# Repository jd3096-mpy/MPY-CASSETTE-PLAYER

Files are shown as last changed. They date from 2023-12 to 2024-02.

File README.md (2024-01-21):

# MPY-CASSETTE-PLAYER

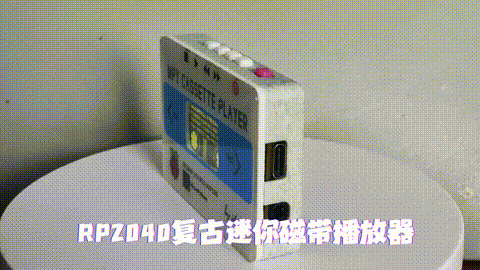
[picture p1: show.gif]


2023年最后一个项目啦，今年尝试了画PCB和3d建模，已经达到了HELLO WORLD水平，可喜可贺！

可识别的封面需要手动添加，主打一个情怀，分辨率要求240x75，添加工具也在文件夹工具脚本下面

img下所有素材都是我用ps一点一点抠的

首发DF论坛，参加树莓派活动！

## 按键功能简介

*按住STOP键，再按POWER键开机则进入boot下载模式，可直接拖拽UF2下载固件*

| | STOP | PLAY | N/V+ | N/V- | POWER |
| ---- | --- | --- | --- | --- | --- |
| 短按 | 暂停 | 播放 | 音量加 | 音量减 | 屏幕开关 |
| 中按 | | 切换封面/歌名 | | | 关机 |
| 长按 | 歌曲选择 | 设置菜单 | 下一首 | 上一首 | 硬关机 |

## 引脚分布

| 引脚名称 | GPIO |
| --- | ---- |
| xcs（VS1053） | 20 |
| x_reset（VS1053） | 21 |
| xdcs（VS1053） | 26 |
| dreq（VS1053） | 27 |
| sck（VS1053和tf卡公用）  | 18 |
| mosi（VS1053和tf卡公用） | 19 |
| miso（VS1053和tf卡公用） | 16 |
| cs（tf卡） | 17 |
| reset（屏幕） | 9 |
| cs（屏幕） | 7 |
| dc（屏幕） | 8 |
| bl（屏幕） | 6 |
| sck（屏幕） | 10 |
| mosi（屏幕） | 11 |
| next（按键） | 14 |
| prev（按键） | 15 |
| play（按键） | 4 |
| mode（按键） | 5 |
| SCL（AXP199） | 1 |
| SDA（AXP199） | 0 |
| IRQ（AXP199） | 2 |

## 重点的技术突破

- 自己学了mp3的编码格式，码率，ID3信息，专辑封面都能自由获取
- 感谢老李eggfly的神级助攻，画了精致的pcb并且通过修改源码让mpy文件系统支持了中文，牛哇！
- 细挖了st7789的驱动库，有个类似精灵的方法，可以在不费内存的情况下保持高速刷屏，很关键，内存终于不紧张了！
- m0dular帮重做了外壳，果然结构科学多了，致敬!
- 最后还是决定去掉了快进快退的功能，效果不好而且不是很常用

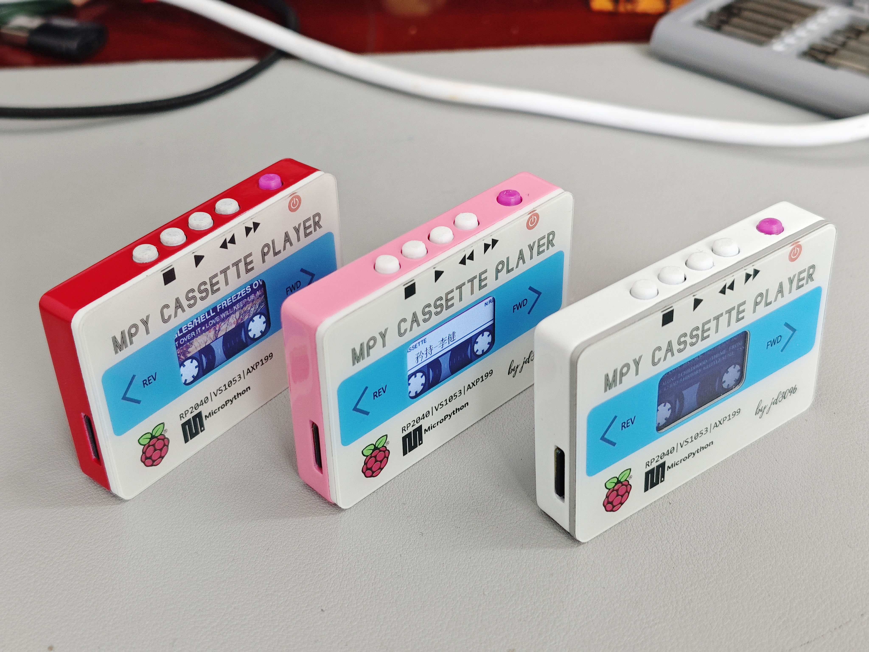
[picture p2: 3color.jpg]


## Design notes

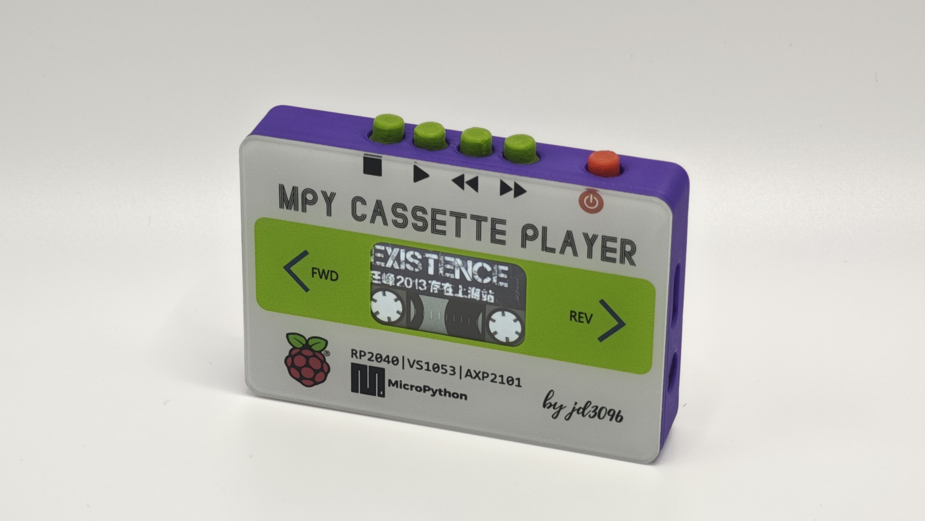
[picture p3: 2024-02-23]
EVA-1.jpg

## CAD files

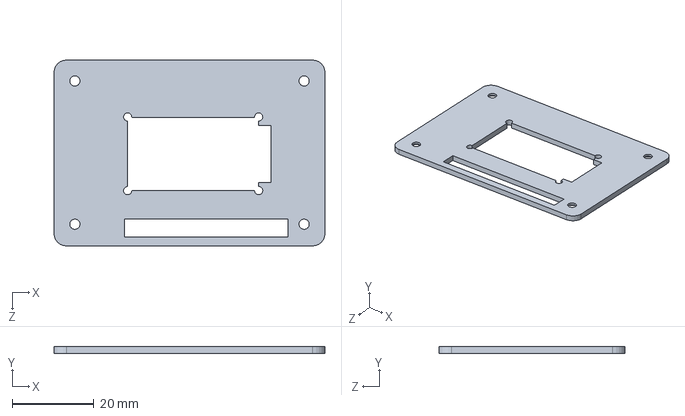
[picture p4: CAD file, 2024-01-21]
外壳/v2(好友m0dular提供)/前板.SLDPRT
66.2 x 1.60 x 45.4 mm

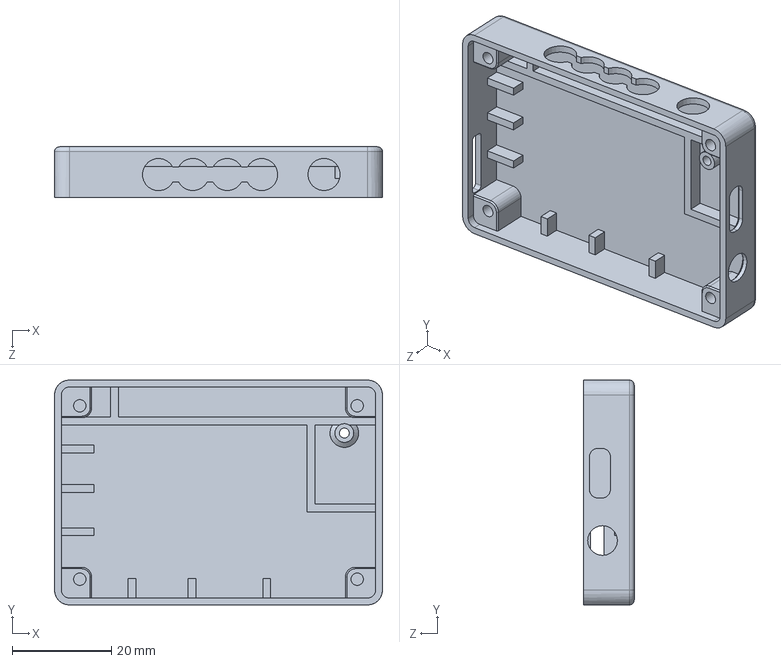
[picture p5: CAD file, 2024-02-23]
外壳/V4/底壳.SLDPRT
66.2 x 45.4 x 10.2 mm

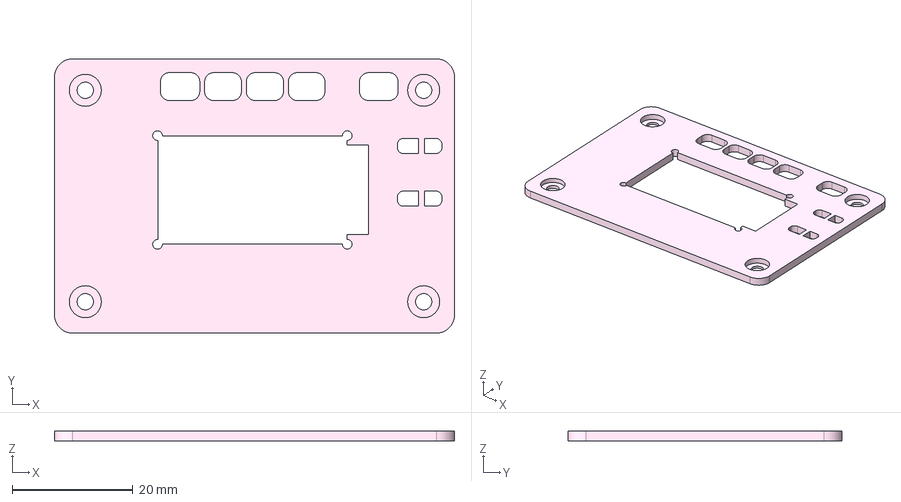
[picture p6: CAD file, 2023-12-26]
外壳/v2(好友m0dular提供)/上壳.step
66.2 x 45.4 x 1.70 mm

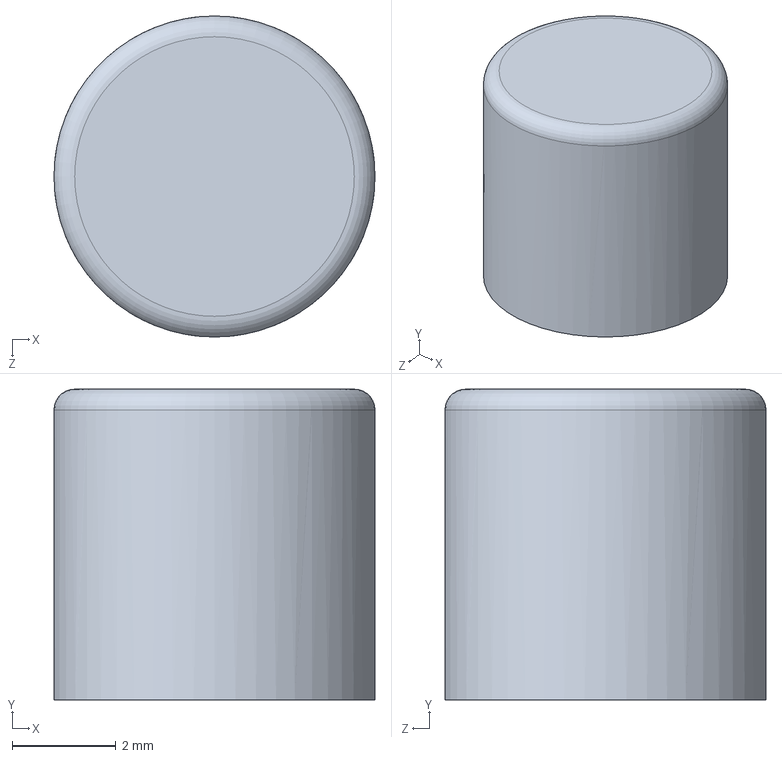
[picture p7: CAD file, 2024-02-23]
外壳/V4/按键.SLDPRT
6.20 x 6.00 x 6.20 mm

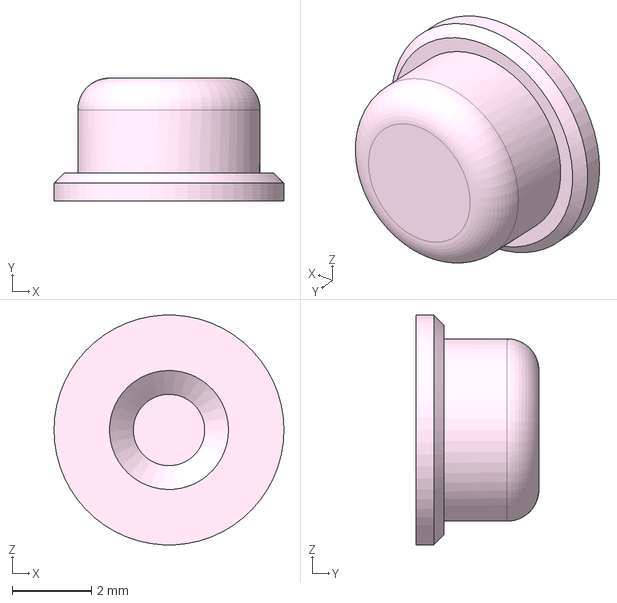
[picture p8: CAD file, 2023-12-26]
外壳/v2(好友m0dular提供)/按键.step
5.80 x 3.10 x 5.79 mm

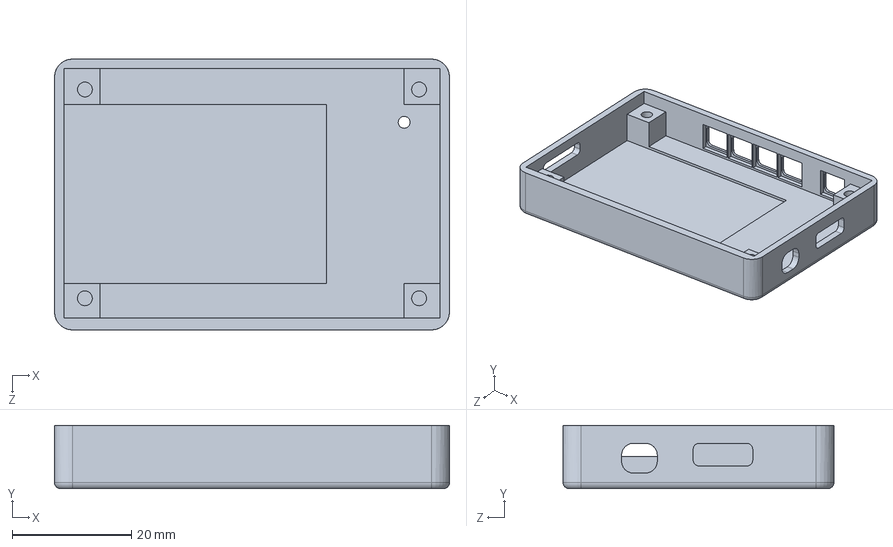
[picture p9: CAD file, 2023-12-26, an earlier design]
外壳/v1/底板.SLDPRT
66.2 x 10.6 x 45.4 mm

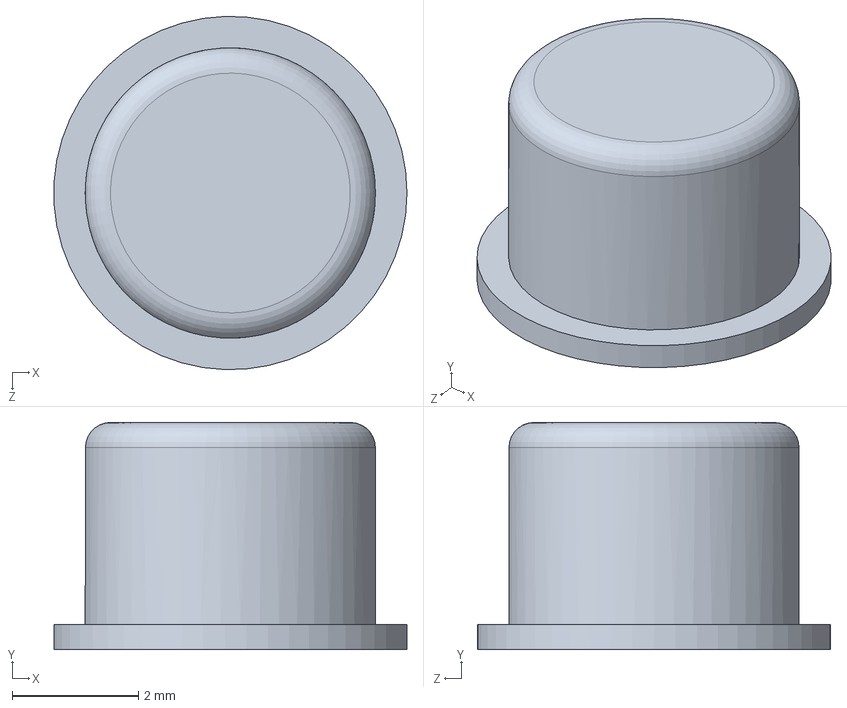
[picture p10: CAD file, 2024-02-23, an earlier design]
外壳/V3/按键.SLDPRT
5.59 x 3.60 x 5.60 mm

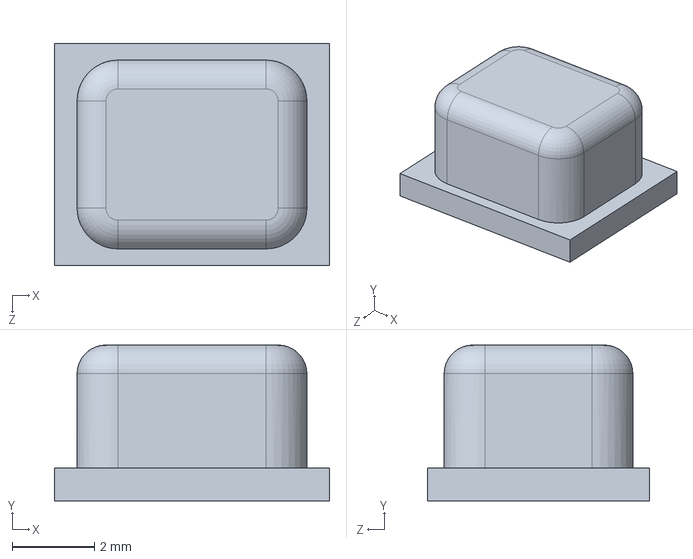
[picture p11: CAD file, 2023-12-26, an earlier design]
外壳/v1/播放按钮.SLDPRT
6.70 x 3.80 x 5.40 mm

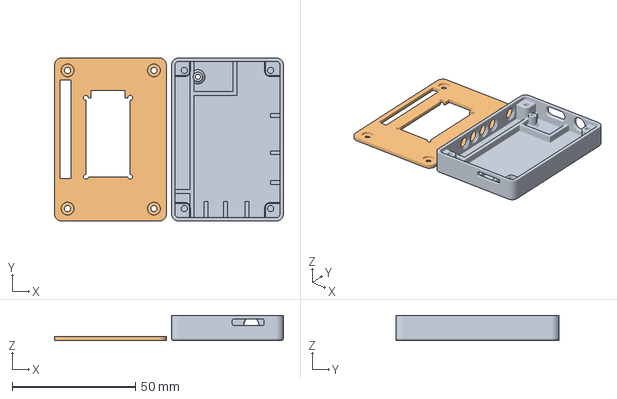
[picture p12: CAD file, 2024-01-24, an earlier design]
外壳/V3/外壳套装 按键另外打比较好.3mf
92.8 x 66.2 x 10.2 mm
底壳.stl
前板.STL

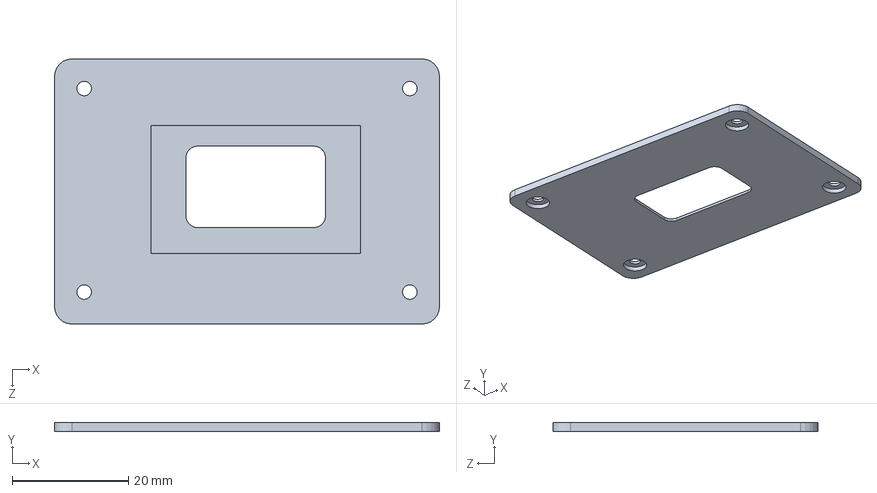
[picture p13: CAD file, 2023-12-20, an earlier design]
外壳/v1/前板.SLDPRT
66.2 x 1.60 x 45.6 mm

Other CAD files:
外壳/V4/前板.SLDPRT
外壳/v2(好友m0dular提供)/底壳.step
外壳/V3/底壳.SLDPRT
外壳/V3/底壳.stl
外壳/V3/按键.3mf
外壳/V3/按键.STL
外壳/V4/前板.STL
外壳/V4/底壳.stl
外壳/V4/按键.STL
外壳/v1/前板.STL
外壳/v1/底板.STL
外壳/v1/播放按钮.STL
外壳/v2(好友m0dular提供)/底壳.stl
外壳/v2(好友m0dular提供)/按键.SLDPRT
外壳/v2(好友m0dular提供)/按键.STL

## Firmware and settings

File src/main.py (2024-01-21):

from machine import Pin
b=Pin(4,Pin.IN,Pin.PULL_UP)

def boot_mode():
    import machine
    import st7789
    import time
    from machine import Pin
    import tft_config
    bl=Pin(6,Pin.OUT)
    bl.value(0)
    tft=tft_config.config(1)
    tft.init()
    tft.fill(0xffff)
    tft.jpg('img/update.jpg',0,0,st7789.SLOW)
    time.sleep(2)
    s=Pin(5,Pin.IN,Pin.PULL_UP)
    while s.value()==1:
        pass
    machine.bootloader(True)
    
if b.value()==0:
    boot_mode()
#----------------------MAIN-------------------------
import gc
gc.enable()
import uasyncio as asyncio
from lib.cassette import CASSETTE
gc.collect()
tape=CASSETTE()
asyncio.run(tape.main())    

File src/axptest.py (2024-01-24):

'''
@license MIT License

Copyright (c) 2022 lewis he

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
@file      AXP2101_AllFunction.py
@author    Lewis He (lewishe@outlook.com)
@date      2022-10-20

'''
from AXP2101 import *
import time

SDA = None
SCL = None
IRQ = None
I2CBUS = None

if implementation.name == 'micropython':
    from machine import Pin, SoftI2C
    SDA = 0
    SCL = 1
    IRQ = 2
    I2CBUS = SoftI2C(scl=Pin(SCL), sda=Pin(SDA))
if implementation.name == 'circuitpython':
    import digitalio
    import board
    import busio
    SDA = board.IO42
    SCL = board.IO41
    IRQ = board.IO6
    I2CBUS = busio.I2C(SCL, SDA)
pmu_flag = False
irq = None


def __callback(args):
    global pmu_flag
    pmu_flag = True
    # print('callback')


PMU = AXP2101(I2CBUS, addr=AXP2101_SLAVE_ADDRESS)

id = PMU.getChipID()
if id != XPOWERS_AXP2101_CHIP_ID:
    print("PMU is not online...")
    while True:
        pass

print('getID:%s' % hex(PMU.getChipID()))

#  Set the minimum common working voltage of the PMU VBUS input,
#  below this value will turn off the PMU
PMU.setVbusVoltageLimit(PMU.XPOWERS_AXP2101_VBUS_VOL_LIM_4V36)

#  Set the maximum current of the PMU VBUS input,
#  higher than this value will turn off the PMU
PMU.setVbusCurrentLimit(PMU.XPOWERS_AXP2101_VBUS_CUR_LIM_1500MA)

#  Get the VSYS shutdown voltage
vol = PMU.getSysPowerDownVoltage()
print('->  getSysPowerDownVoltage:%u' % vol)

#  Set VSY off voltage as 2600mV, Adjustment range 2600mV ~ 3300mV
PMU.setSysPowerDownVoltage(2600)

vol = PMU.getSysPowerDownVoltage()
print('->  getSysPowerDownVoltage:%u' % vol)

#  DC1 IMAX = 2A
#  1500~3400mV, 100mV/step, 20steps
PMU.setDC1Voltage(3300)
# print('DC1  : %s   Voltage:%u mV ' % PMU.isEnableDC1()  ? '+': '-', PMU.getDC1Voltage())
print('DC1  : {0}   Voltage:{1} mV '.format(
    ('-', '+')[PMU.isEnableDC1()], PMU.getDC1Voltage()))


#  DC2 IMAX = 2A
#  500~1200mV  10mV/step, 71steps
#  1220~1540mV 20mV/step, 17steps
PMU.setDC2Voltage(1000)
print(PMU.isEnableDC2())
print('DC2  : {0}   Voltage:{1} mV '.format(
    ('-', '+')[PMU.isEnableDC2()], PMU.getDC2Voltage()))

#  DC3 IMAX = 2A
#  500~1200mV, 10mV/step, 71steps
#  1220~1540mV, 20mV/step, 17steps
#  1600~3400mV, 100mV/step, 19steps
PMU.setDC3Voltage(3300)
print('DC3  : {0}   Voltage:{1} mV '.format(
    ('-', '+')[PMU.isEnableDC3()], PMU.getDC3Voltage()))

#  DCDC4 IMAX = 1.5A
#  500~1200mV, 10mV/step, 71steps
#  1220~1840mV, 20mV/step, 32steps
PMU.setDC4Voltage(1000)
print('DC4  : {0}   Voltage:{1} mV '.format(
    ('-', '+')[PMU.isEnableDC4()], PMU.getDC4Voltage()))

#  DC5 IMAX = 2A
#  1200mV
#  1400~3700mV, 100mV/step, 24steps
PMU.setDC5Voltage(3300)
print('DC5  : {0}   Voltage:{1} mV '.format(
    ('-', '+')[PMU.isEnableDC5()], PMU.getDC5Voltage()))

# ALDO1 IMAX = 300mA
# 500~3500mV, 100mV/step, 31steps
PMU.setALDO1Voltage(3300)

# ALDO2 IMAX = 300mA
# 500~3500mV, 100mV/step, 31steps
PMU.setALDO2Voltage(3300)

# ALDO3 IMAX = 300mA
# 500~3500mV, 100mV/step, 31steps
PMU.setALDO3Voltage(3300)

# ALDO4 IMAX = 300mA
# 500~3500mV, 100mV/step, 31steps
PMU.setALDO4Voltage(3300)

# BLDO1 IMAX = 300mA
# 500~3500mV, 100mV/step, 31steps
PMU.setBLDO1Voltage(3300)

# BLDO2 IMAX = 300mA
# 500~3500mV, 100mV/step, 31steps
PMU.setBLDO2Voltage(3300)

# CPUSLDO IMAX = 30mA
# 500~1400mV, 50mV/step, 19steps
PMU.setCPUSLDOVoltage(1000)

# DLDO1 IMAX = 300mA
# 500~3400mV, 100mV/step, 29steps
PMU.setDLDO1Voltage(3300)

# DLDO2 IMAX = 300mA
# 500~1400mV, 50mV/step, 2steps
PMU.setDLDO2Voltage(3300)

#  PMU.enableDC1()
PMU.enableDC2()
PMU.enableDC3()
PMU.enableDC4()
PMU.enableDC5()
PMU.enableALDO1()
PMU.enableALDO2()
PMU.enableALDO3()
PMU.enableALDO4()
PMU.enableBLDO1()
PMU.enableBLDO2()
PMU.enableCPUSLDO()
PMU.enableDLDO1()
PMU.enableDLDO2()

print('===================================')
print('DC1    : {0}   Voltage:{1} mV '.format(
    ('-', '+')[PMU.isEnableDC1()], PMU.getDC1Voltage()))
print('DC2    : {0}   Voltage:{1} mV '.format(
    ('-', '+')[PMU.isEnableDC2()], PMU.getDC2Voltage()))
print('DC3    : {0}   Voltage:{1} mV '.format(
    ('-', '+')[PMU.isEnableDC3()], PMU.getDC3Voltage()))
print('DC4    : {0}   Voltage:{1} mV '.format(
    ('-', '+')[PMU.isEnableDC4()], PMU.getDC4Voltage()))
print('DC5    : {0}   Voltage:{1} mV '.format(
    ('-', '+')[PMU.isEnableDC5()], PMU.getDC5Voltage()))
print('===================================')
print('ALDO1  : {0}   Voltage:{1} mV '.format(
    ('-', '+')[PMU.isEnableALDO1()], PMU.getALDO1Voltage()))
print('ALDO2  : {0}   Voltage:{1} mV '.format(
    ('-', '+')[PMU.isEnableALDO2()], PMU.getALDO2Voltage()))
print('ALDO3  : {0}   Voltage:{1} mV '.format(
    ('-', '+')[PMU.isEnableALDO3()], PMU.getALDO3Voltage()))
print('ALDO4  : {0}   Voltage:{1} mV '.format(
    ('-', '+')[PMU.isEnableALDO4()], PMU.getALDO4Voltage()))
print('===================================')
print('BLDO1  : {0}   Voltage:{1} mV '.format(
    ('-', '+')[PMU.isEnableBLDO1()], PMU.getBLDO1Voltage()))
print('BLDO2  : {0}   Voltage:{1} mV '.format(
    ('-', '+')[PMU.isEnableBLDO2()], PMU.getBLDO2Voltage()))
print('===================================')
print('CPUSLDO: {0}   Voltage:{1} mV '.format(
    ('-', '+')[PMU.isEnableCPUSLDO()], PMU.getCPUSLDOVoltage()))
print('===================================')
print('DLDO1  : {0}   Voltage:{1} mV '.format(
    ('-', '+')[PMU.isEnableDLDO1()], PMU.getDLDO1Voltage()))
print('DLDO2  : {0}   Voltage:{1} mV '.format(
    ('-', '+')[PMU.isEnableDLDO2()], PMU.getDLDO2Voltage()))
print('===================================')

#  Set the time of pressing the button to turn off
powerOff = ['4', '6', '8', '10']
PMU.setPowerKeyPressOffTime(PMU.XPOWERS_POWEROFF_6S)
opt = PMU.getPowerKeyPressOffTime()
print('PowerKeyPressOffTime: %s Sceond' % powerOff[opt])


#  Set the button power-on press time
powerOn = ['128ms', '512ms', '1000ms', '2000ms']
PMU.setPowerKeyPressOnTime(PMU.XPOWERS_POWERON_2S)
opt = PMU.getPowerKeyPressOnTime()
print('PowerKeyPressOnTime: %s ' % powerOn[opt])


print('===================================')

#  DCDC 120 % (130 %) high voltage turn off PMIC function
en = PMU.getDCHighVoltagePowerDowmEn()
print('getDCHighVoltagePowerDowmEn:%s' % ('DISABLE', 'ENABLE')[en])

#  DCDC1 85 % low voltage turn off PMIC function
en = PMU.getDC1LowVoltagePowerDowmEn()
print('getDC1LowVoltagePowerDowmEn:%s' % ('DISABLE', 'ENABLE')[en])

#  DCDC2 85 % low voltage turn off PMIC function
en = PMU.getDC2LowVoltagePowerDowmEn()
print('getDC2LowVoltagePowerDowmEn:%s' % ('DISABLE', 'ENABLE')[en])

#  DCDC3 85 % low voltage turn off PMIC function
en = PMU.getDC3LowVoltagePowerDowmEn()
print('getDC3LowVoltagePowerDowmEn:%s' % ('DISABLE', 'ENABLE')[en])

#  DCDC4 85 % low voltage turn off PMIC function
en = PMU.getDC4LowVoltagePowerDowmEn()
print('getDC4LowVoltagePowerDowmEn:%s' % ('DISABLE', 'ENABLE')[en])

#  DCDC5 85 % low voltage turn off PMIC function
en = PMU.getDC5LowVoltagePowerDowmEn()
print('getDC5LowVoltagePowerDowmEn:%s' % ('DISABLE', 'ENABLE')[en])
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

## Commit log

2023-12-08 smt shell
    [button.SLDPRT, rw_bottom.SLDPRT, rw_top.SLDPRT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]
2023-12-14 shell and logo
    [前板.SLDPRT, 底板.SLDPRT]
2023-12-20 first edtion
    [前板.STL, 底板.SLDPRT, 底板.STL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]
2023-12-24 chinese file name support
    [播放按钮.SLDPRT, 播放按钮.STL]
2023-12-25 enable adc
    [底板.SLDPRT, 底板.STL]
2023-12-26 jpg mem sd umount
    [上壳.step, 前板.SLDPRT, 前板.STL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]
2024-01-18 shell v3
    [前板.SLDPRT, 前板.STL, 底壳.SLDPRT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]
2024-01-21 shell 0.1mm
    [前板.SLDPRT, 前板.STL, 底壳.SLDPRT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]
2024-01-24 folder finished
    [外壳套装 按键另外打比较好.3mf, 拓竹壳一套.3mf, 按键.3mf]
